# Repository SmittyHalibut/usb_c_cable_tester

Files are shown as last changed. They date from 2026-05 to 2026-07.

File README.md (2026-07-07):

# USB Cable Tester

Simple board to test various USB cables! (Note the USB standard helps to identify these [USB-C](https://www.usb.org/usb-type-cr-cable-and-connector-specification), cables that are compliant with the standard will have selected pins according to [cable and connector specification release](https://www.usb.org/sites/default/files/USB%20Type-C%202.2%20Release%20202210%20%281%29.zip)). 

Plug in your cable to both sides and see which signals light up!

**FOR CABLE USE ONLY. DO NOT EVER PLUG THIS IN TO A DEVICE, THE PINS ON ONE SIDE ARE ALL SHORTED TOGETHER AND THAT COULD BREAK IT!**

Board Front

Board Back

## Board Variants

There are three variants of the board, each living in its own directory with the KiCad
source and ordering instructions. Pick the one that fits how you want to build it:

| Variant | Folder | Best for | Ordering |
|---|---|---|---|
| **Hand-solder** | [`hand-solder/`](hand-solder/) | DIY builds — through-hole-friendly parts from Digikey/Mouser, easy to solder and rework | [ordering](hand-solder/ORDERING.md) |
| **JLCPCB SMD** | [`jlcpcb-smd/`](jlcpcb-smd/) | Cheapest fully-assembled boards using current JLCPCB stock | [ordering](jlcpcb-smd/ORDERING.md) |
| **JLCPCB vertical** | [`jlcpcb-vertical/`](jlcpcb-vertical/) | Newest design (v3.0) — vertical connectors, through-hole where possible | [ordering](jlcpcb-vertical/ORDERING.md) |

Each folder is a self-contained KiCad project — open the `.kicad_pro` inside it.

## Related Projects!
@coryalder made a neat [3d printed/laser cut case](https://github.com/coryalder/usb-c-tester-case). Check it out! (But make sure it's for the correct version, since components have changed)

[@foorschtbar@chaos.social](https://mastodon.social/@foorschtbar@chaos.social) made a really nice 3D printed case (multicolor). You can [find it here.](https://www.printables.com/model/1003847-usb-cable-tester-multicolor-case)

## License
USB Cable Tester © 2024 by Alvaro Prieto is licensed under CC BY 4.0. To view a copy of this license, visit http://creativecommons.org/licenses/by/4.0/

The v3.0 (vertical) variant includes modifications © 2026 by Mark Smith, Halibut Electronics Inc. Same license applies.

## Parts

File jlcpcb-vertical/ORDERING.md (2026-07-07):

# Ordering Instructions for v3.0 boards on [JLCPCB](https://jlcpcb.com/) — vertical variant

This is the v3.0 design with **vertical connectors** and through-hole parts where possible.  Assembly can either be done by hand, or using JLCPCB.

If you intend to assemble by hand, follow this process up to "PCB Assembly".  Order the boards, but skip the assembly process.  Then look at the very bottom of this document for information on sourcing parts.

## Generate Files

This directory contains the KiCad source only. Generate the manufacturing files from
`usb_c_cable_tester.kicad_pcb` in this folder.

* Install the **Fabrication Toolkit** plugin to KiCAD.
* Tools → External Plugins → Fabrication Toolkit.
* Make sure the following is checked:
  * Apply automatic fill for all zones
* Uncheck the following:
  * Open browser after generation
  * Generate backup files
* The rest aren't important. Click **Generate**

This generates the following files you'll use below:

* Gerbers: `production/USB_Cable_Tester_[version].zip`
* Bill of Materials: `production/bom.csv`
* Positions: `production/positions.csv`
* ...and a few others you won't use.

## Upload Gerbers and Select PCB Parameters

Go to JLCPCB, click on "instant quote" or "order now" and upload the gerber zip in the `production/` folder.

Select the following settings (or change how you like them)

* ENIG will look better, but it's a bit more expensive. I definitely recommend lead free HASL at the very least
* Choose your color, it's free.  :-)
* All other defaults are fine.

> **If you intend to assemble the board yourself, then DO NOT select "PCB Assembly" and proceed straight to the "Checkout!" step below.**

If you DO intend to use JLCPCB for assembly, then continue.  Near the bottom of the page, select "PCB Assembly" and select the following settings (or change how you like them):

* PCBA Type: **Economic**
* Assembly Side: **Top Side**
* All other defaults are fine.

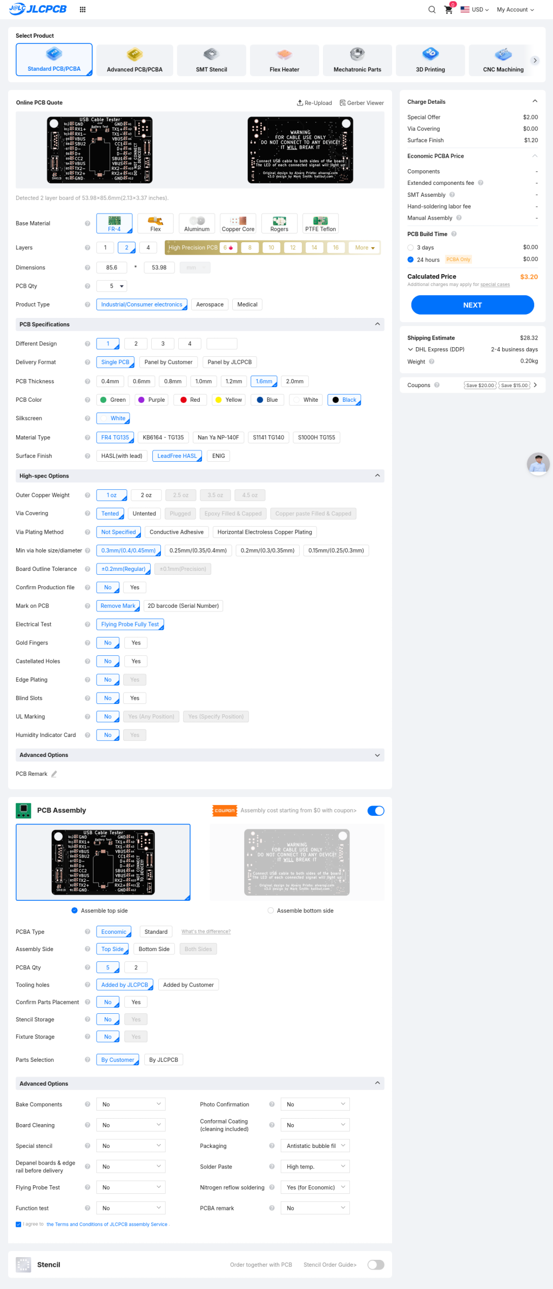
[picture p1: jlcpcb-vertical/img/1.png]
Selection page


Click **Next**

The next page lets you review your board.  Click **Next** again.

## Upload BOM and Placement files

Upload the `bom.csv` and `positions.csv` files.  Click on the "Upload" buttons and select the files from earlier.

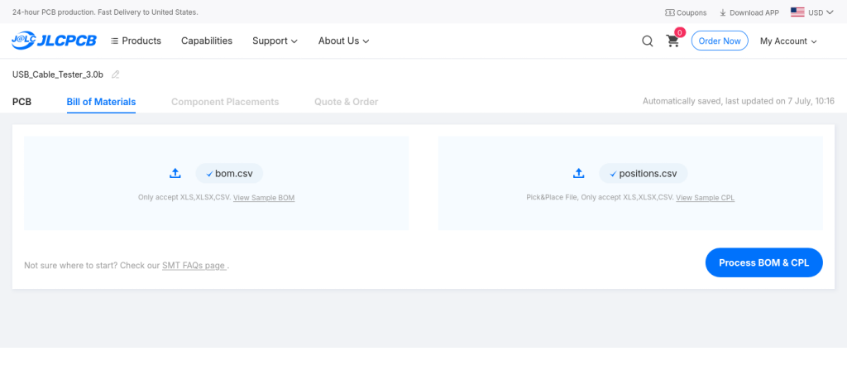
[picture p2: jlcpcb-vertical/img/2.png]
Upload BOM


Click **Process BOM & CPL**

## Verify Bill Of Materials

Verify the BOM.  The important part to verify is that all parts are available and selected.  If a part is no longer available, you'll have to find a suitable replacement.

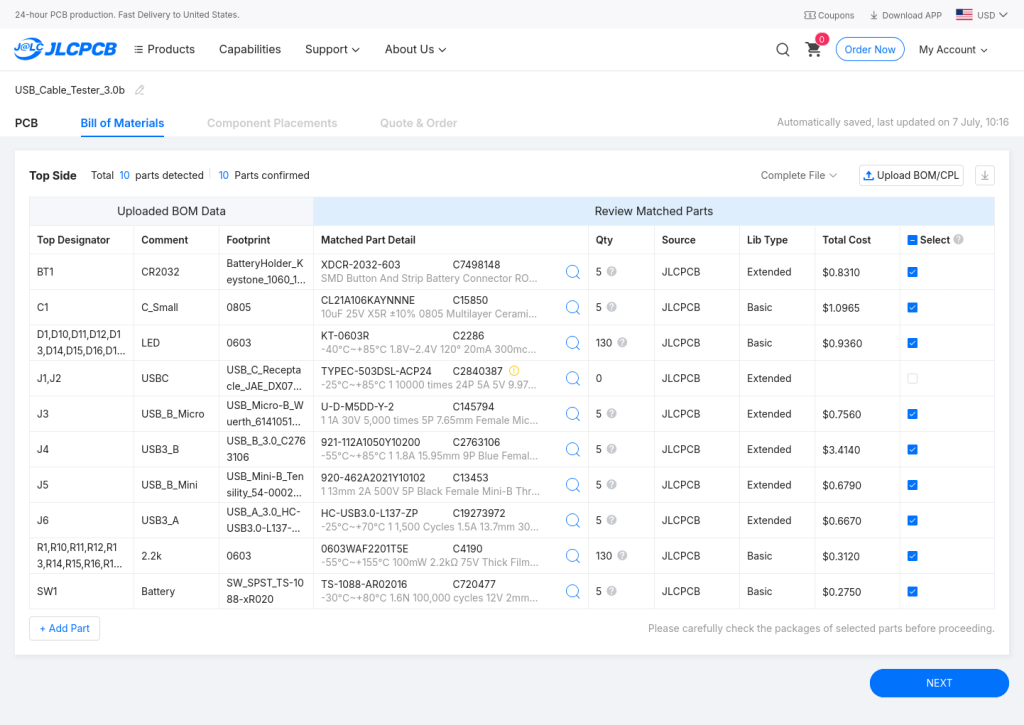
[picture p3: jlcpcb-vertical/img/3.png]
BOM


Some parts (J1,J2 shown below) might have a yellow notification icon, and be unselected.  In this case, it's because the USB-C sockets require a $0.03 upcharge because they're difficult to place.  The important part here is to make sure you select the part for assembly, the blue check box on the far right.

Yellow Alert

Click **Next**

## Fix Component Placement

Verify component placement (it's not quite right by default).  Rotate and move parts so that the pins line up in the holes correctly.

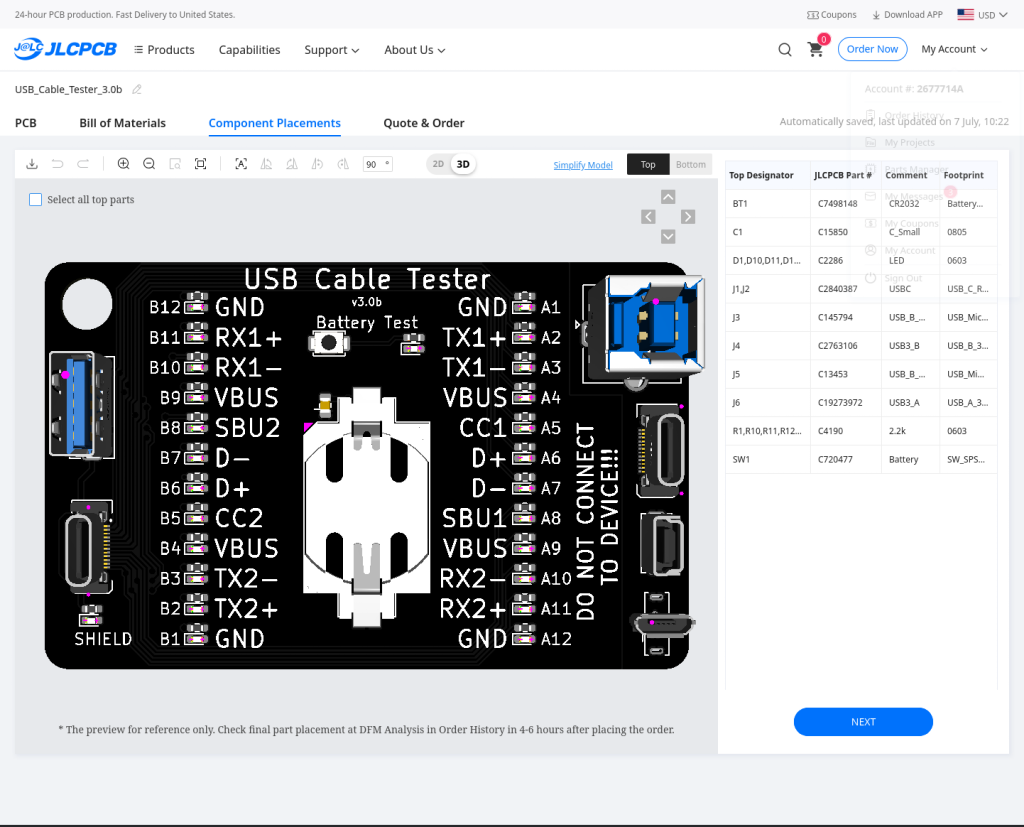
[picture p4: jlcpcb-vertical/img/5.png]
front of board


Then select each USB connector and use the arrows on the top right to move it into place.  Change the view to "2D" and "Bottom" and make sure the pins line up with the holes.

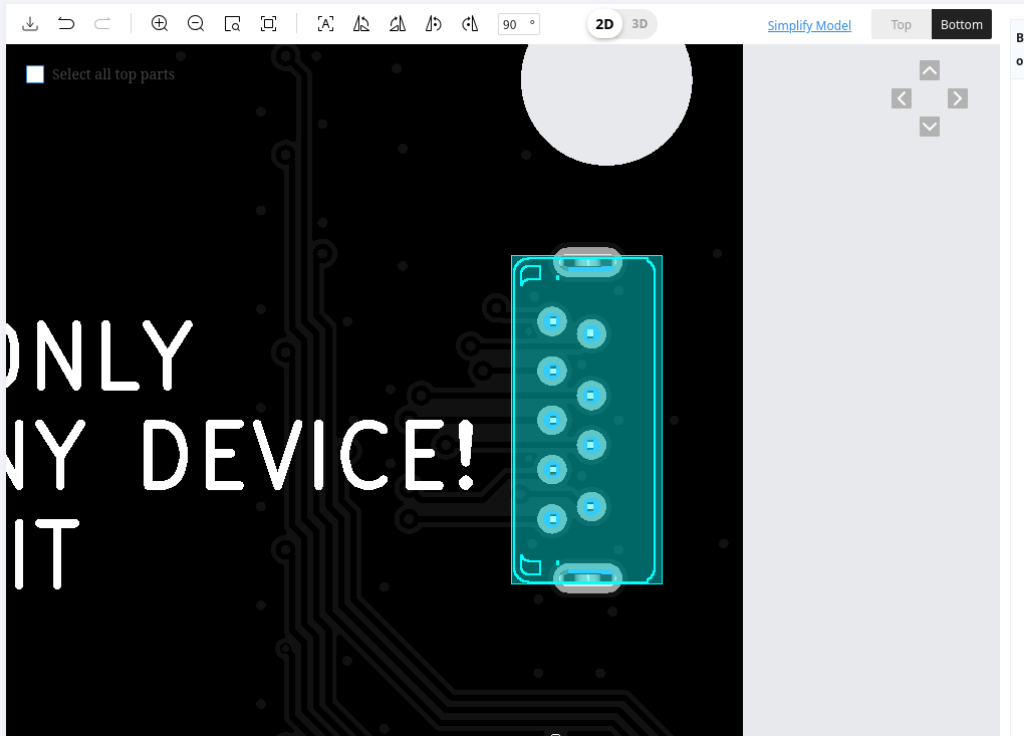
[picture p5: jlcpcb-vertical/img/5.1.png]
back of board


At time of writing, the MicroUSB socket defaults to rotated 90 deg.  Rotate it and line it up:

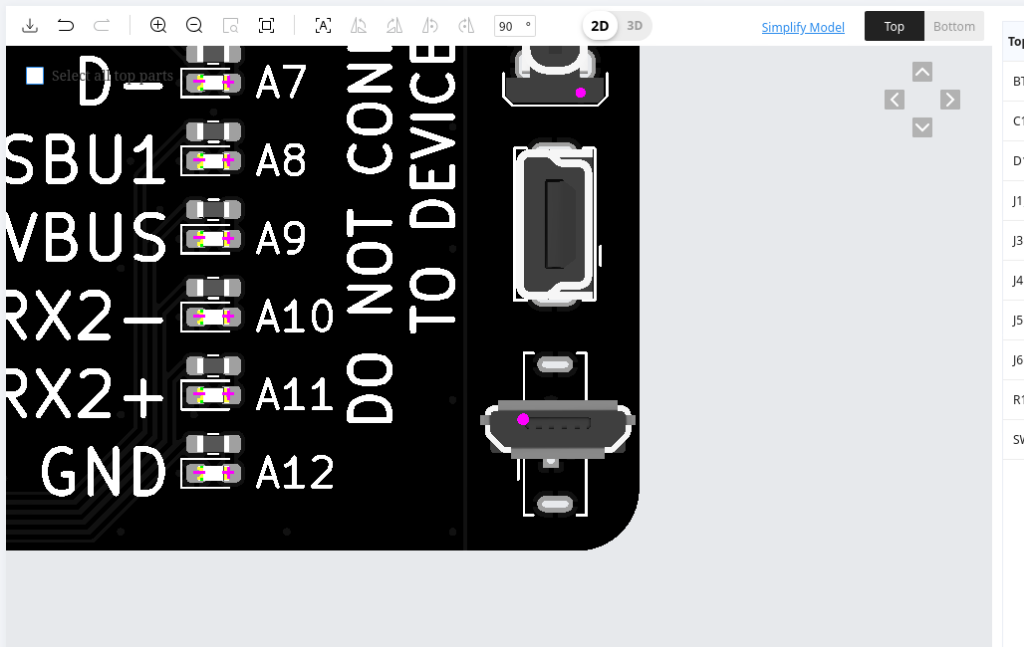
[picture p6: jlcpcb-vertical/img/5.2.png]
microUSB socket


The 3d view is also quite useful when trying to line things up

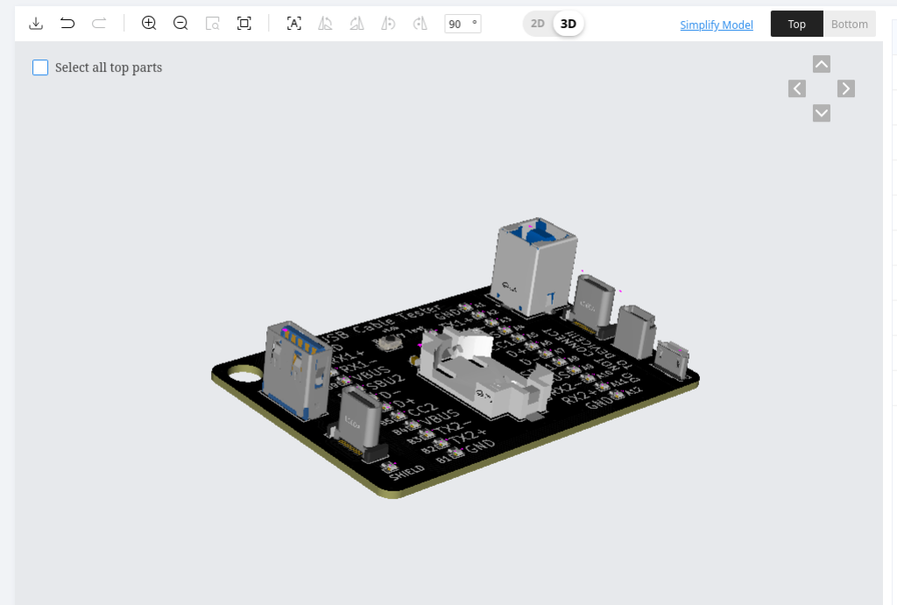
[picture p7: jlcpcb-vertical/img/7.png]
3d view


Click **Next**

## Quote & Order

The next page shows you a breakdown of costs.  You'll need to provide a "Product Description."  I pick something in the "DIY" category.

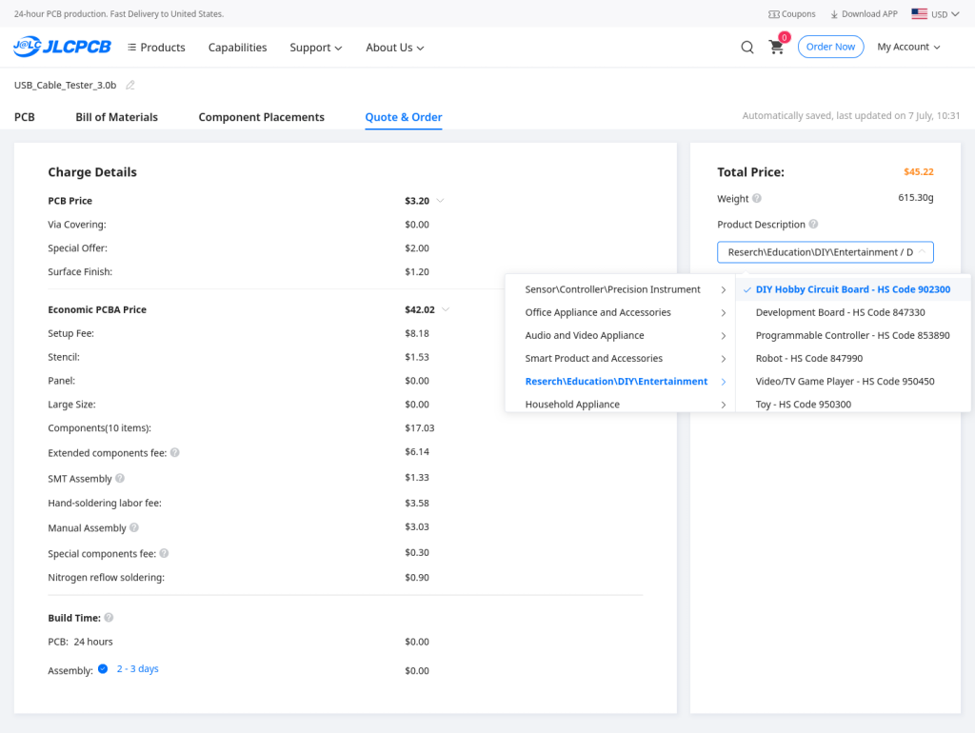
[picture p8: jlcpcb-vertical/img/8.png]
Quote & Order


Click **Save To Cart**

## Checkout!

Checkout!

## Additional Notes

### All pins soldered together

[There have been reports](https://github.com/alvarop/usb_c_cable_tester/issues/15) of JLC asking if all the pins on one side should be shorted together. The answer is yes, this is on purpose :D

### Ordering parts for manual assembly

The bill of materials (bom.csv) contains parts, descriptions, and LCSC part numbers.  For common parts like the resistors and LEDs, you can buy just about any alternative from Mouser, Digikey, eBay, etc.

However, some of the USB sockets (mostly USB-C) have very specific board layout requirements.  I suggest you buy those parts from LCSC, using the LCSC part numbers in the BOM.  Alternatively, if you try to find a different source, make sure the footprint is the same.  You can find the footprint drawings in the data sheet linked to from the LCSC page for the parts.

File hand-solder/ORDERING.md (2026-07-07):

# Ordering & Assembly Instructions — hand-solder variant

This variant is designed to be **hand-assembled** with through-hole-friendly parts you can
buy from Digikey/Mouser. You order **bare boards only** (no PCB assembly) and solder the
components yourself, which makes the boards much cheaper.

## 1. Generate gerbers
This directory contains the KiCad source only. Open `usb_c_cable_tester.kicad_pcb` in this
folder and export gerbers: *File → Plot* → Gerbers, then *Generate Drill Files*. Zip the
output directory.

## 2. Order bare PCBs
Upload the gerber zip to any fab ([JLCPCB](https://jlcpcb.com/), OSH Park, etc.).

* Do **NOT** select PCB Assembly — order bare boards only.
* Lead-free HASL is fine; ENIG looks nicer if you want to spend a bit more.
* Pick any color, it's usually free.

## 3. Source components and solder
Populate the board by hand using the parts in the BOM (`usb_c_cable_tester_BOM.csv` /
`usb_c_cable_tester.xml` exported from the schematic). All parts are commonly available from
Digikey/Mouser.

## Additional Notes
[There have been reports](https://github.com/alvarop/usb_c_cable_tester/issues/15) of fabs
asking if all the pins on one side should be shorted together. The answer is yes, this is on
purpose :D

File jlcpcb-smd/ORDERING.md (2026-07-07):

# Ordering Instructions on [JLCPCB](https://jlcpcb.com/) — SMD variant

This is the surface-mount variant, designed to be **fully assembled** by JLCPCB using
parts from their stock (cheapest option for a finished board).

## Generate Files
This directory contains the KiCad source only. Generate the manufacturing files from
`usb_c_cable_tester.kicad_pcb` in this folder:

* **Gerbers** — KiCad PCB editor → *File → Plot* → Gerbers, then *Generate Drill Files*
* **BOM** + **Component Positions (CPL)** — *File → Fabrication Outputs* (or the
  Fabrication Toolkit plugin)

Pre-built bundles are also attached to the [releases page](https://github.com/alvarop/usb_c_cable_tester/releases/).

## Upload Gerbers and Select PCB Parameters
Go to JLCPCB, click on "instant quote" or "order now" and upload the gerber zip.

***MAKE SURE YOU SELECT 0.8mm BOARD THICKNESS*** otherwise, the USB-C connector soldering will be unreliable at best.

Select the following settings (or change how you like them)
> ENIG will look better, but it's a bit more expensive. I definitely recommend lead free HASL at the very least

Selection page

Make sure you select PCB Assembly as well then click Next

# Upload BOM and Placement files

Upload BOM

Verify BOM

BOM

## Fix Component Placement
Verify component placement (it's not quite right by default)

First, rotate the battery holder 90 degrees to the left
component placement
 
Then select each USB connector and use the arrows on the top right to move it into place
front of board

You can change the view to the back to make sure the pins line up

back of board

The 3d view is also quite useful when trying to line things up

3d view

## Checkout!

Checkout!

## Additional Notes
[There have been reports](https://github.com/alvarop/usb_c_cable_tester/issues/15) of JLC asking if all the pins on one side should be shorted together. The answer is yes, this is on purpose :D

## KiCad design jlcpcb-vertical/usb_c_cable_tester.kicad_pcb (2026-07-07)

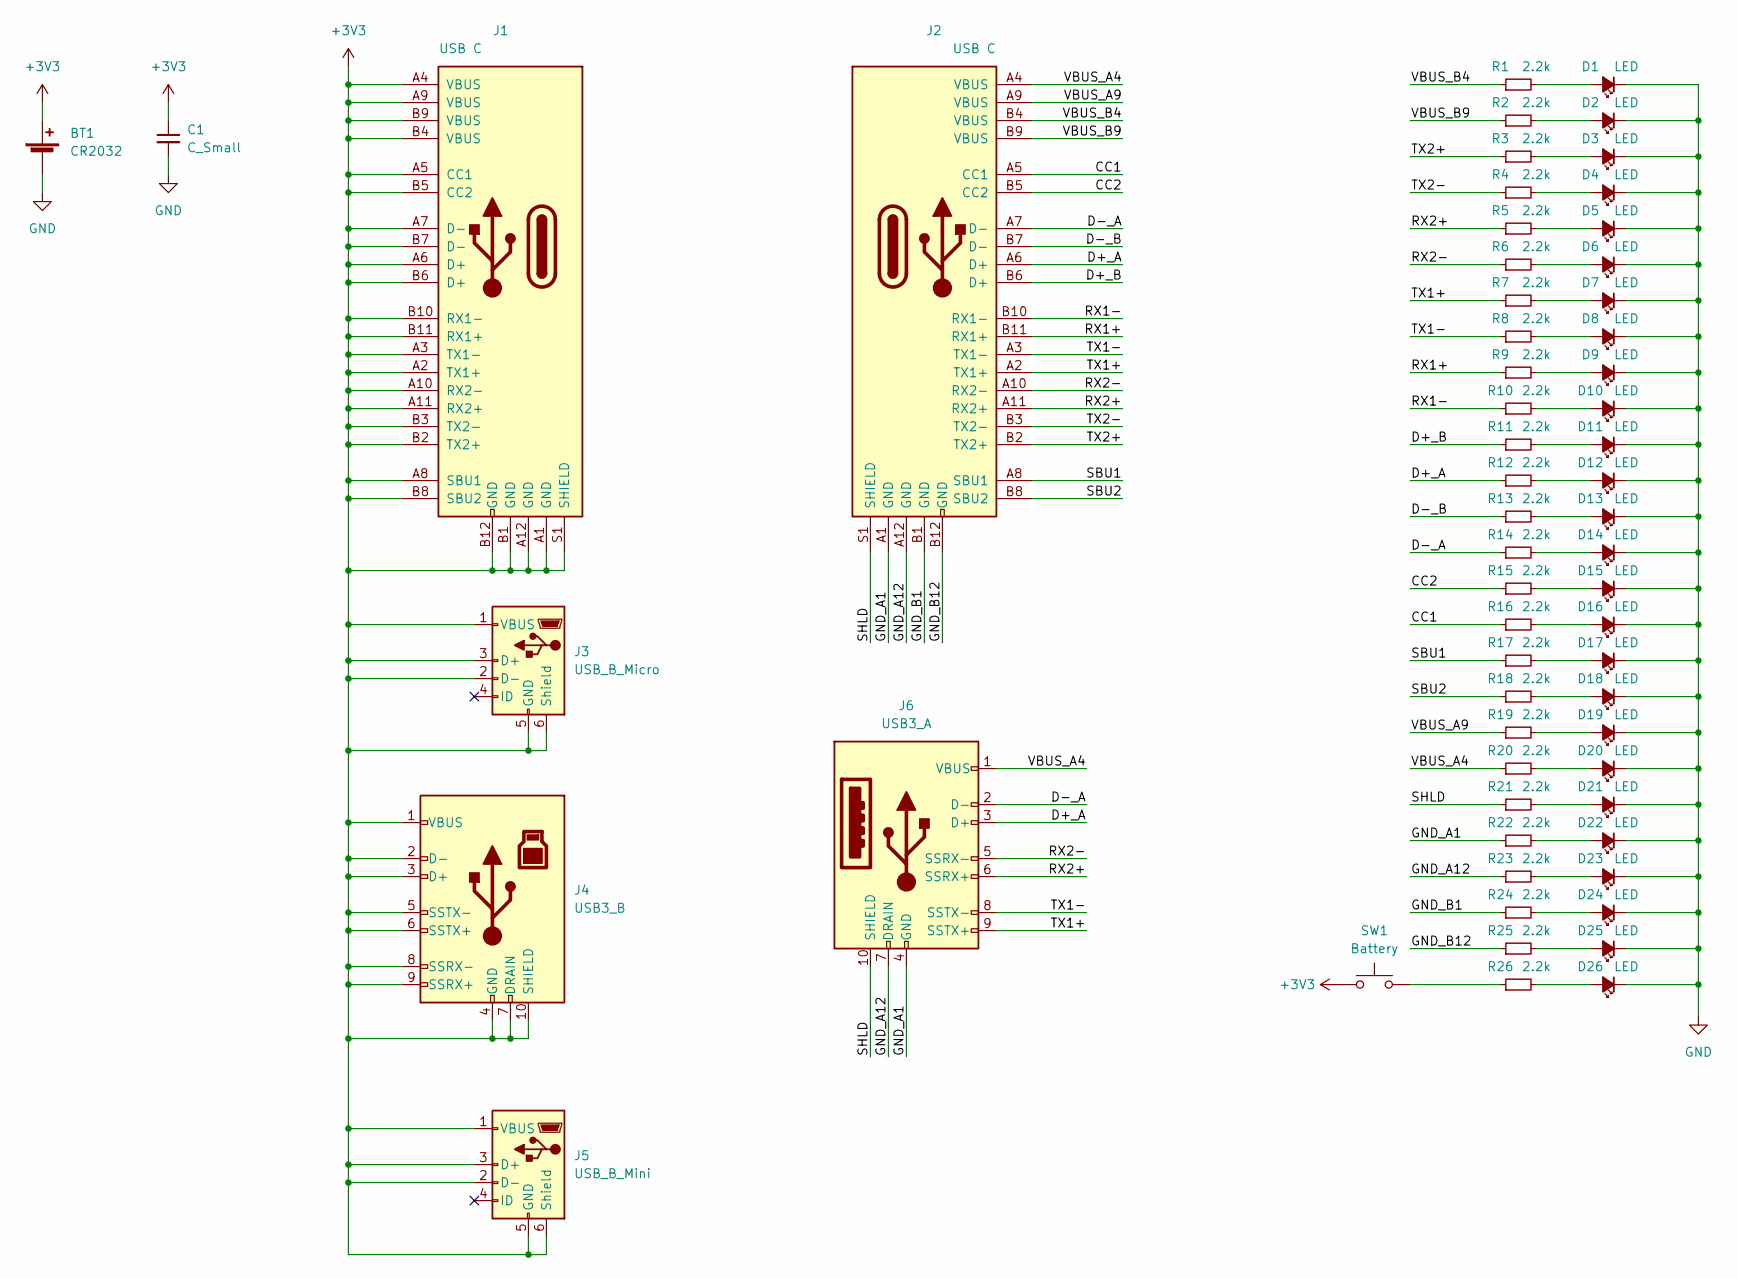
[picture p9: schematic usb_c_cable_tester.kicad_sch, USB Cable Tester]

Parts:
BT1: CR2032; BatteryHolder_Keystone_1060_1x2032; LCSC C7498148
C1: C_Small; C_0805_2012Metric_Pad1.18x1.45mm_HandSolder; LCSC C15850
D1, D2, D3, D4, D5, D6, D7, D8, D9, D10, D11, D12, D13, D14, D15, D16, D17, D18, D19, D20, D21, D22, D23, D24, D25, D26: LED; LED_0603_1608Metric_Pad1.05x0.95mm_HandSolder; LCSC C2286
J1, J2: USB C; USB_C_Receptacle_JAE_DX07S024WJ3R400; LCSC C2840387
J3: USB_B_Micro; USB_Micro-B_Wuerth_614105150721_Vertical; LCSC C145794
J4: USB3_B; USB_B_3.0_C2763106; LCSC C2763106
J5: USB_B_Mini; USB_Mini-B_Tensility_54-00023_Vertical; LCSC C13453
J6: USB3_A; USB_A_3.0_HC-USB3.0-L137-ZP_C19273972; LCSC C19273972
R1, R2, R3, R4, R5, R6, R7, R8, R9, R10, R11, R12, R13, R14, R15, R16, R17, R18, R19, R20, R21, R22, R23, R24, R25, R26: 2.2k; R_0603_1608Metric_Pad0.98x0.95mm_HandSolder; LCSC C4190
SW1: Battery; SW_SPST_TS-1088-xR020; LCSC C720477

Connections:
+3V3: BT1.1 (+), C1.1, J1.A1 (GND), J1.A2 (TX1+), J1.A3 (TX1-), J1.A4 (VBUS), J1.A5 (CC1), J1.A6 (D+), J1.A7 (D-), J1.A8 (SBU1), J1.A9 (VBUS), J1.A10 (RX2-), J1.A11 (RX2+), J1.A12 (GND), J1.B1 (GND), J1.B2 (TX2+), J1.B3 (TX2-), J1.B4 (VBUS), J1.B5 (CC2), J1.B6 (D+), J1.B7 (D-), J1.B8 (SBU2), J1.B9 (VBUS), J1.B10 (RX1-), J1.B11 (RX1+), J1.B12 (GND), J1.S1 (SHIELD), J3.1 (VBUS), J3.2 (D-), J3.3 (D+), J3.5 (GND), J3.6 (Shield), J4.1 (VBUS), J4.2 (D-), J4.3 (D+), J4.4 (GND), J4.5 (SSTX-), J4.6 (SSTX+), J4.7 (DRAIN), J4.8 (SSRX-), J4.9 (SSRX+), J4.10 (SHIELD), J5.1 (VBUS), J5.2 (D-), J5.3 (D+), J5.5 (GND), J5.6 (Shield), SW1.1
/CC1: J2.A5 (CC1), R16.1
/CC2: J2.B5 (CC2), R15.1
/D+_A: J2.A6 (D+), J6.3 (D+), R12.1
/D+_B: J2.B6 (D+), R11.1
/D-_A: J2.A7 (D-), J6.2 (D-), R14.1
/D-_B: J2.B7 (D-), R13.1
/GND_A1: J2.A1 (GND), J6.4 (GND), R22.1
/GND_A12: J2.A12 (GND), J6.7 (DRAIN), R23.1
/GND_B1: J2.B1 (GND), R24.1
/GND_B12: J2.B12 (GND), R25.1
/RX1+: J2.B11 (RX1+), R9.1
/RX1-: J2.B10 (RX1-), R10.1
/RX2+: J2.A11 (RX2+), J6.6 (SSRX+), R5.1
/RX2-: J2.A10 (RX2-), J6.5 (SSRX-), R6.1
/SBU1: J2.A8 (SBU1), R17.1
/SBU2: J2.B8 (SBU2), R18.1
/SHLD: J2.S1 (SHIELD), J6.10 (SHIELD), R21.1
/TX1+: J2.A2 (TX1+), J6.9 (SSTX+), R7.1
/TX1-: J2.A3 (TX1-), J6.8 (SSTX-), R8.1
/TX2+: J2.B2 (TX2+), R3.1
/TX2-: J2.B3 (TX2-), R4.1
/VBUS_A4: J2.A4 (VBUS), J6.1 (VBUS), R20.1
/VBUS_A9: J2.A9 (VBUS), R19.1
/VBUS_B4: J2.B4 (VBUS), R1.1
/VBUS_B9: J2.B9 (VBUS), R2.1
GND: BT1.2 (-), C1.2, D1.1 (K), D2.1 (K), D3.1 (K), D4.1 (K), D5.1 (K), D6.1 (K), D7.1 (K), D8.1 (K), D9.1 (K), D10.1 (K), D11.1 (K), D12.1 (K), D13.1 (K), D14.1 (K), D15.1 (K), D16.1 (K), D17.1 (K), D18.1 (K), D19.1 (K), D20.1 (K), D21.1 (K), D22.1 (K), D23.1 (K), D24.1 (K), D25.1 (K), D26.1 (K)
unnamed: D1.2 (A), R1.2
unnamed: D2.2 (A), R2.2
unnamed: D3.2 (A), R3.2
unnamed: D4.2 (A), R4.2
unnamed: D5.2 (A), R5.2
unnamed: D6.2 (A), R6.2
unnamed: D7.2 (A), R7.2
unnamed: D8.2 (A), R8.2
unnamed: D9.2 (A), R9.2
unnamed: D10.2 (A), R10.2
unnamed: D11.2 (A), R11.2
unnamed: D12.2 (A), R12.2
unnamed: D13.2 (A), R13.2
unnamed: D14.2 (A), R14.2
unnamed: D15.2 (A), R15.2
unnamed: D16.2 (A), R16.2
unnamed: D17.2 (A), R17.2
unnamed: D18.2 (A), R18.2
unnamed: D19.2 (A), R19.2
unnamed: D20.2 (A), R20.2
unnamed: D21.2 (A), R21.2
unnamed: D22.2 (A), R22.2
unnamed: D23.2 (A), R23.2
unnamed: D24.2 (A), R24.2
unnamed: D25.2 (A), R25.2
unnamed: D26.2 (A), R26.2
unnamed: R26.1, SW1.2

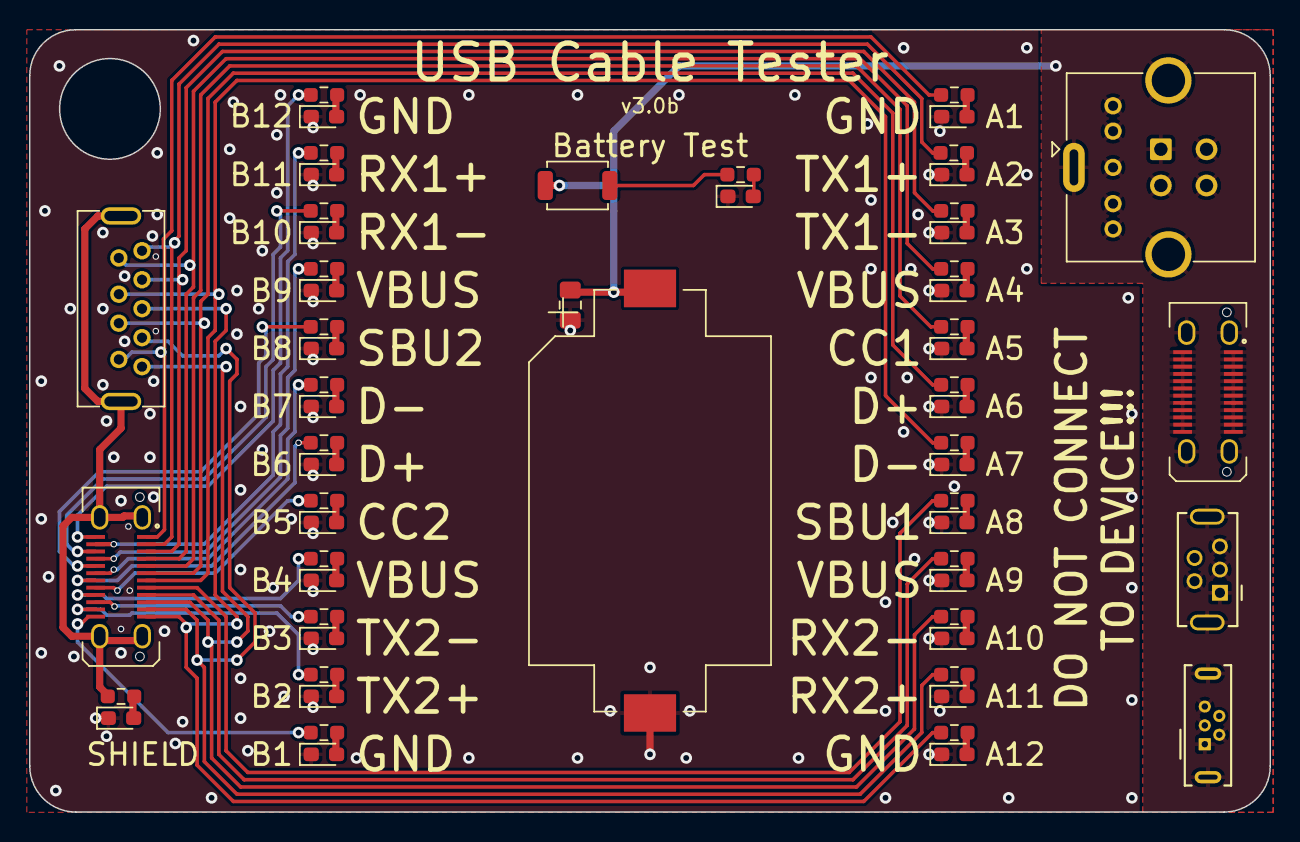
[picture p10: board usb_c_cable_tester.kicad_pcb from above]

Board: 2 copper layers, 85.6 x 54.0 mm, 61 parts (0 on the bottom side), 54 nets.

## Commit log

2026-05-26 Moved from https://github.com/SmittyHalibut/usb_c_cable_tester/tree/v2.2-jlcpcb #32
    [usb_c_cable_tester.kicad_pcb, usb_c_cable_tester.kicad_sch]
2026-05-28 Revert "Merging changes for current (2026 May) JLCPCB stock and ordering."
    [usb_c_cable_tester.kicad_pcb, usb_c_cable_tester.kicad_sch]
2026-06-21 All three variants coexisting in repo
    Took the Hand-solder, JLCPCB, and JLCPCB vertical variants and put them
    in separate subdirectories.
    [usb_c_cable_tester.kicad_pcb, usb_c_cable_tester.kicad_sch]
2026-07-03 Add 0.8mm pcb warning
2026-07-07 jlcpcb-vertical/ v3.0b. Spacing, MicroB with long pins, added battery test.
    [usb_c_cable_tester.kicad_pcb, usb_c_cable_tester.kicad_sch]
2026-07-07 No-op change.
    [usb_c_cable_tester.kicad_pcb]
2026-07-07 Updated ORDERING.md for v3.0 boards and process.
